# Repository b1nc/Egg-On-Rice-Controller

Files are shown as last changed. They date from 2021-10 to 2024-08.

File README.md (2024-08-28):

# Egg On Rice Controller
 Micro hitbox-style controller for arcade games. Utilizes the Brook UFB.
 Heavily inspired by the "Mille-feuille" by Pomeran. https://pomegd.booth.pm/items/2685530
-

**Why is it called "Egg On Rice"? I love egg on rice hell yeah.**

- *Feel free to modify the files to your needs and specifications but credit me for the original files, please.*

- *All of the parts used will be linked or named in the materials.txt file.*

- *The switch footprints were made with Kailh Choc v1 switches in mind.*

- *The keycaps may be too low and sit flush with the top acrylic panel. Please modify either the stem length or the blocker length to your needs.*

- *No RGB because it hurts my eyes. (I'm just too lazy to implement it.)*

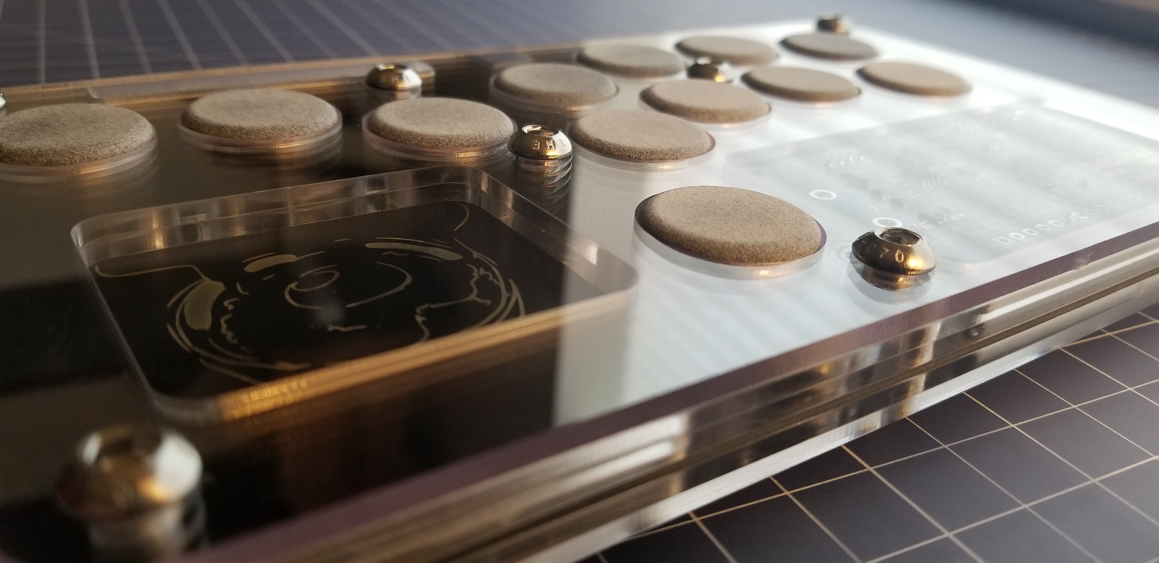
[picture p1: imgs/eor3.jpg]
eorimg1


 USB Type-C Connection because we live in 2020s A.D, not 2020s B.C. Micro USBs should just die.  
 (However, USB-Cs are a pain to hand solder, but again, I'm bad at soldering.)
 
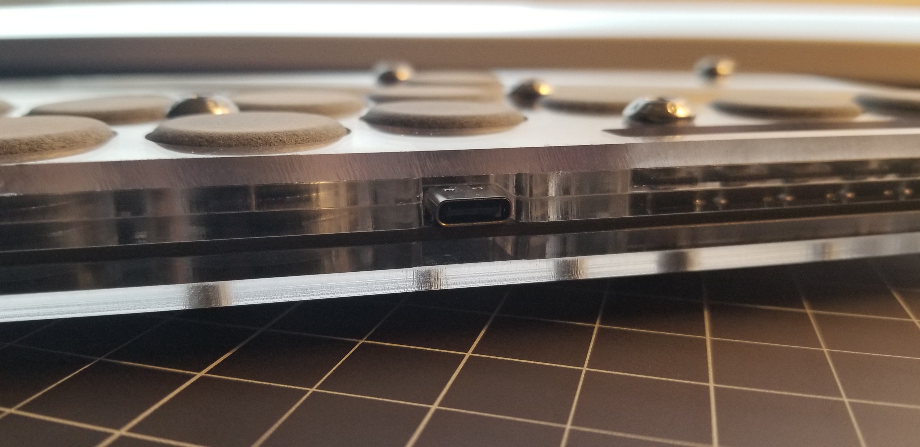
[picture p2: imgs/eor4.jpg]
eorimg2
 
 
 6 tactile push switches for menu navigations.  
 (I don't even own a PS4 or Xbox, what do these buttons even do.)  
 From left to right (in playing position): Home, Touchpad, LSB (huh), RSB (what), Share, Option (the only one I use).
 
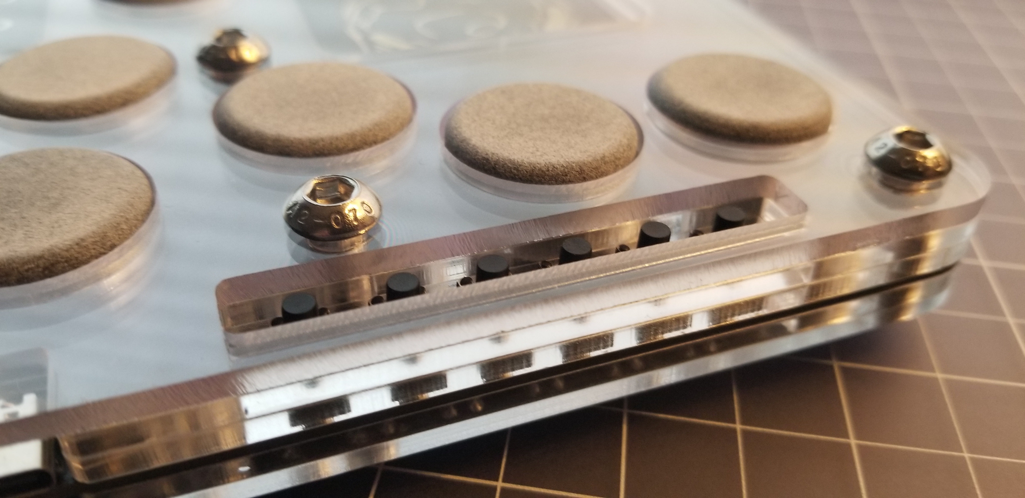
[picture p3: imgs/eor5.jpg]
 
 
 I couldn't find an M6 screw feet without sacrificing the overall thickness of the board, so I made the thing feetless.  
 (The back does kinda look clean, though.)
 
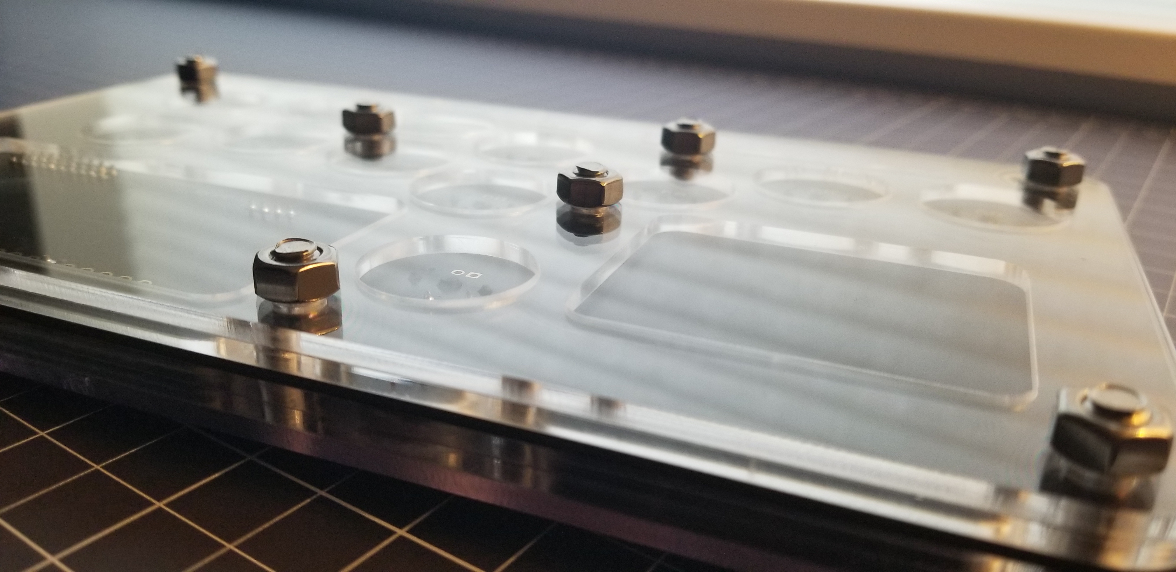
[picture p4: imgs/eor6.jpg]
 
 
 I'm sorry for my bad photography skills.  
   
 Here's a picture of the PCB using a PCB viewer.
 
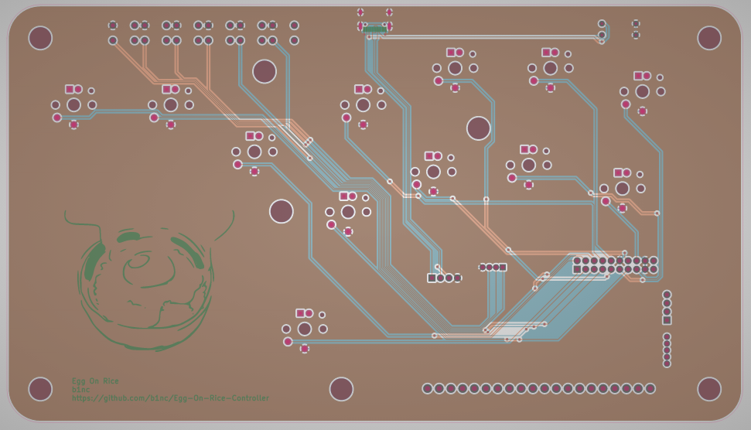
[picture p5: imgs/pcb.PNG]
   

 Buttons.
 
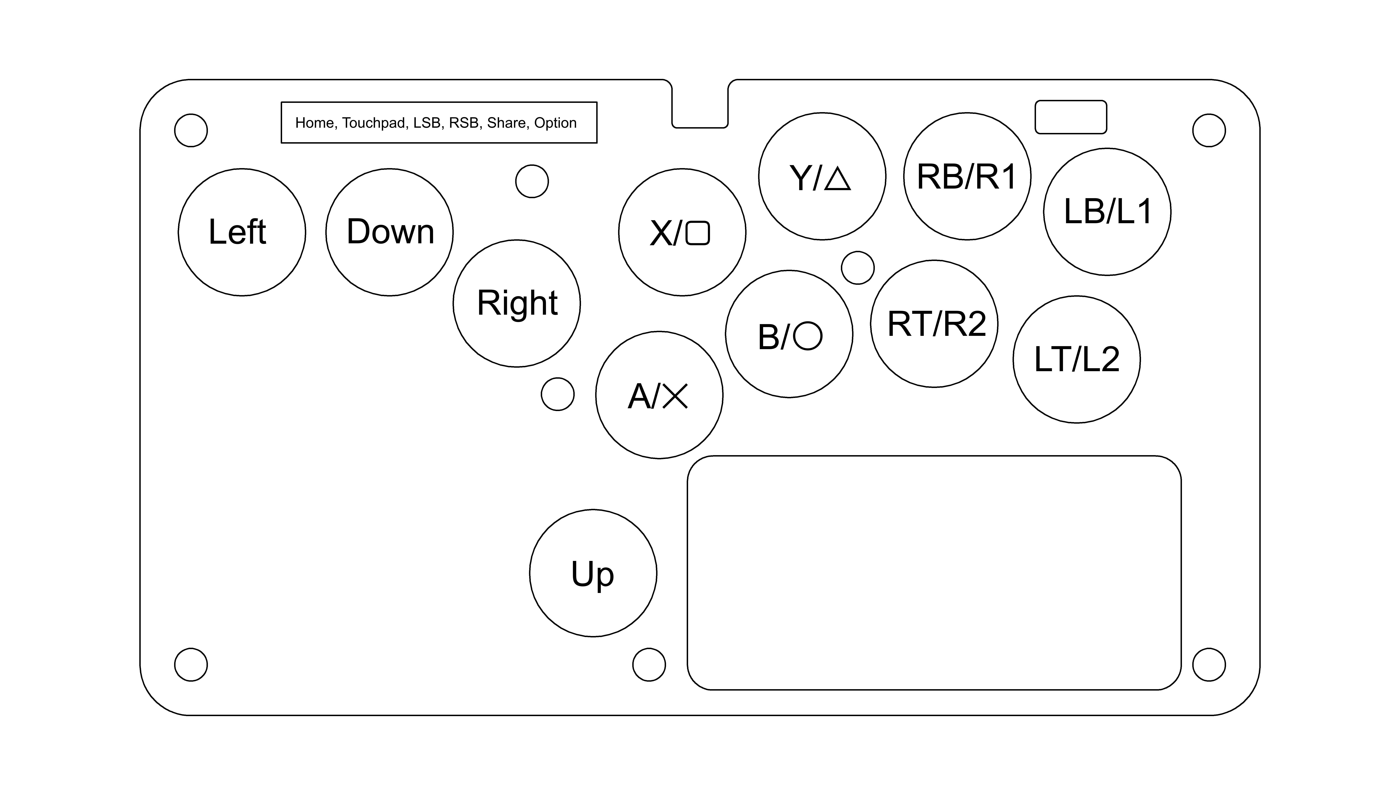
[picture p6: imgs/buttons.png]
  
  
## Design Process ##  
Started with a drawing of the basic outline and layout for the PCB (switches, resistors, push buttons, and UFB).  

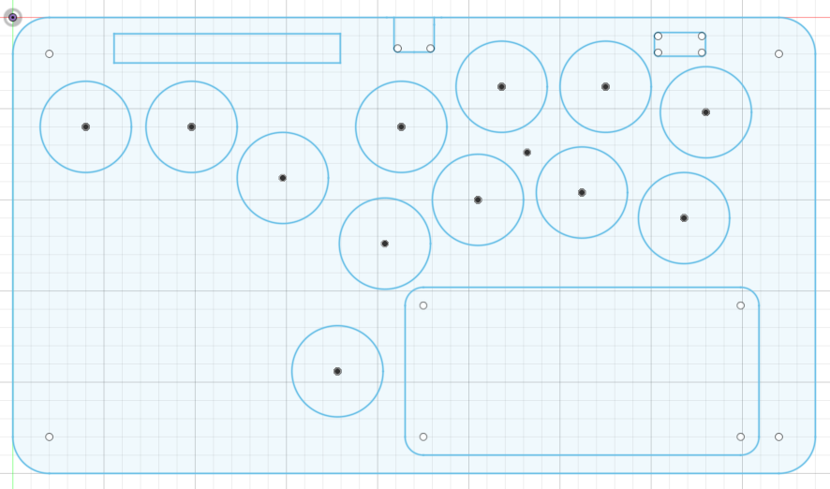
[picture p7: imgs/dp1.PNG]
  

Then exported the sketch as a dxf file and ported it into KiCad for component alignments.

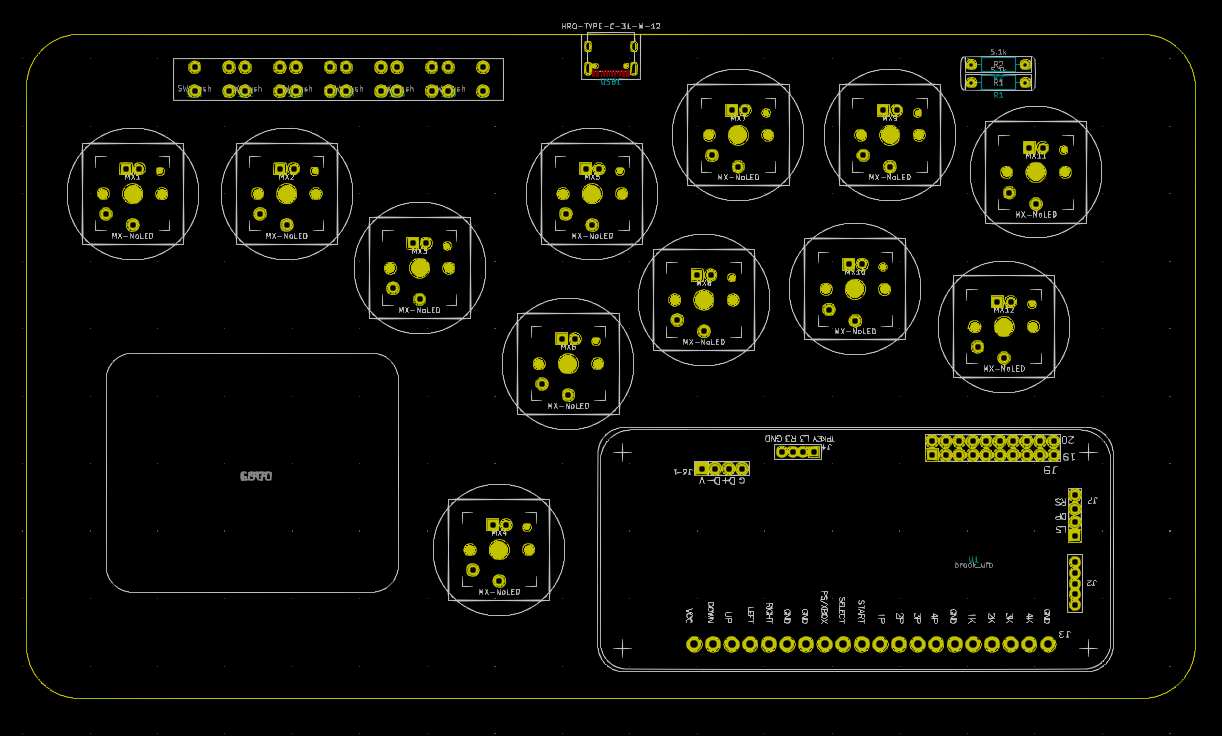
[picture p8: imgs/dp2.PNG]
  

The schematics for this PCB board are extremely simple. The only hard part was failing to find a UFB footprint and having to make my own. (UFB footprint is contained in this project and free to use, while it might not look good, it gets the job done.)

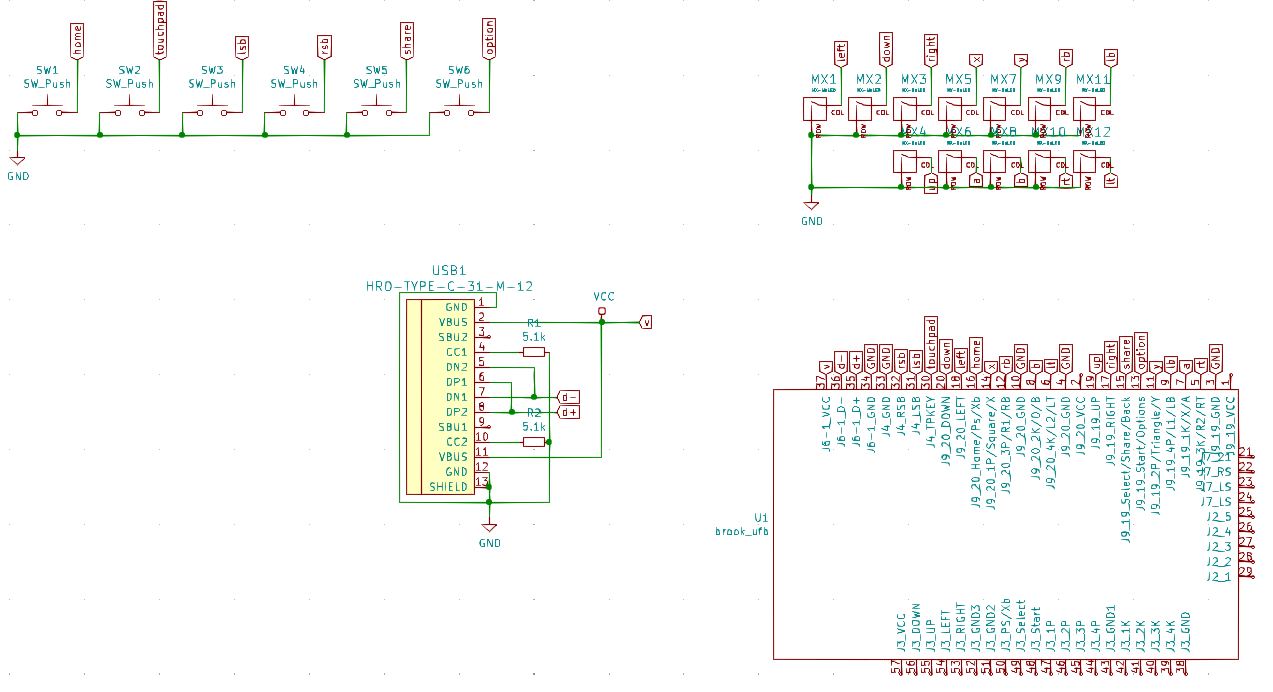
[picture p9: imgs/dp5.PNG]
  

After routing the board, edge cuts are added for M6 screw holes and artwork. (Feel free to edit the files to implement your personal artwork.)

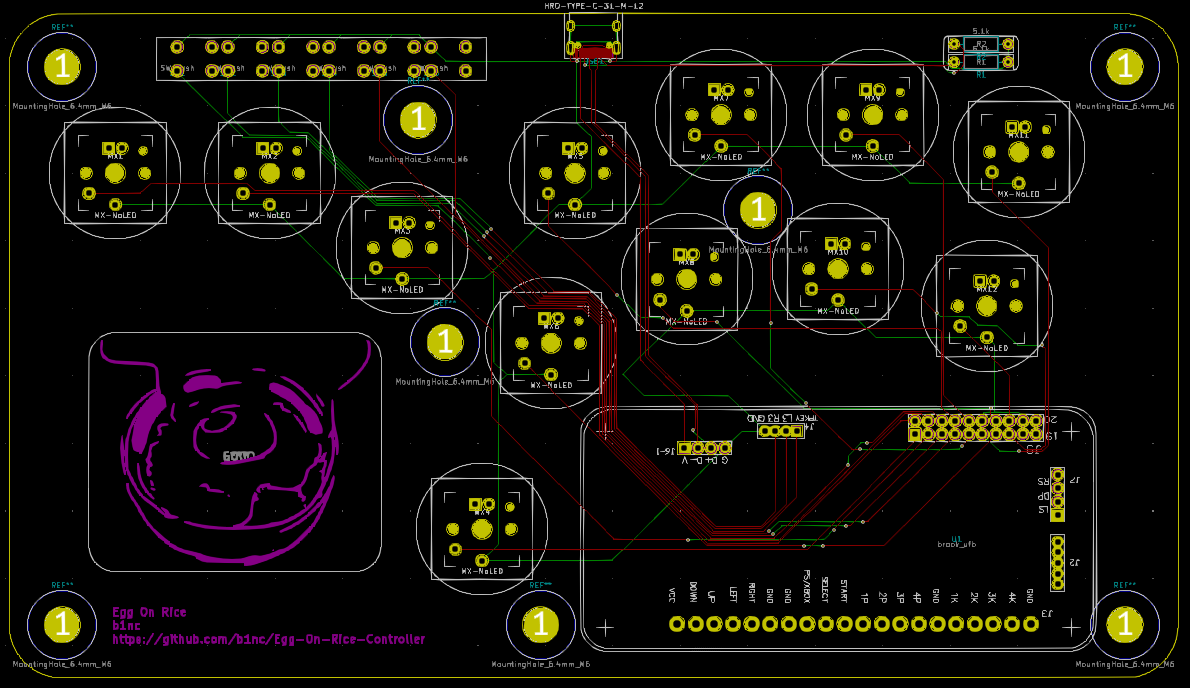
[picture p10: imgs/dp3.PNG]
  

Panel 1 and 2 are adjusted to fit with each other. If artwork isn't a concern, the bottom panel can also be used for the top panel to reduce cutting costs.

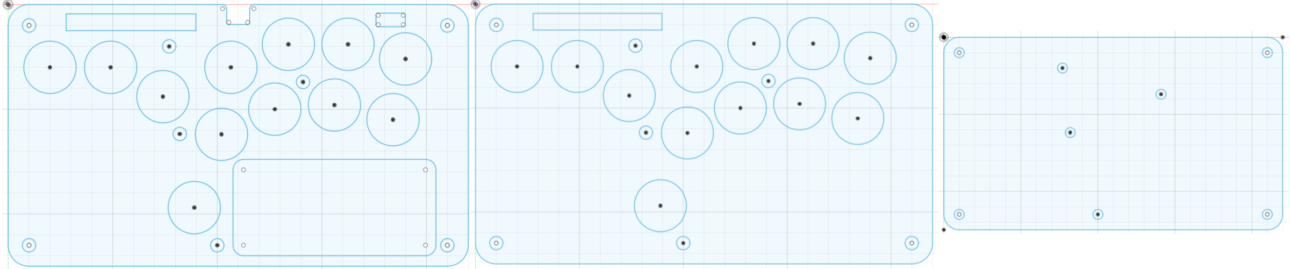
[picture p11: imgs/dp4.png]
  

Cap dimensions are made to fit almost flush with the top panels while the stems are made according to the Kailh Choc v1 datasheet.
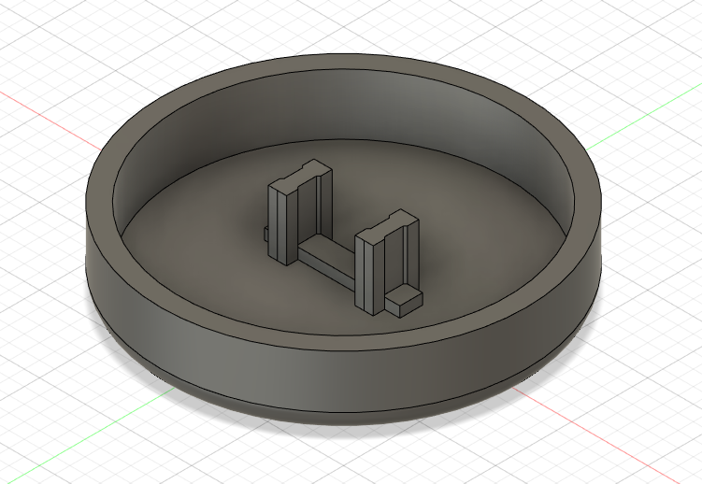
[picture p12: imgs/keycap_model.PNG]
  

## Building Instructions ##
All of the files needed are in this repo.

In the PCB folder, there's a Gerber.zip folder within the Gerber folder. Use this for PCB manufacturing.  
(I used JLCPCB for PCB prototyping.)  
  
In the Acrylic Layers folder, check which set of panels you want to use and use the dxf files for cutting.  
(Please refer to the drawing and readme for panel thickness and amount.)  
(I used SendCutSend laser cutting service for all my acrylic panels.)  
  
The button caps are made for Kailh Choc v1 switches and are in the Button Keycaps folder with both step and stl files available.  
(I don't plan on making keycaps for MX stems, but feel free to modify the files.)  
(Sculpteo has amazing prices for small 3D prints like these caps.)  

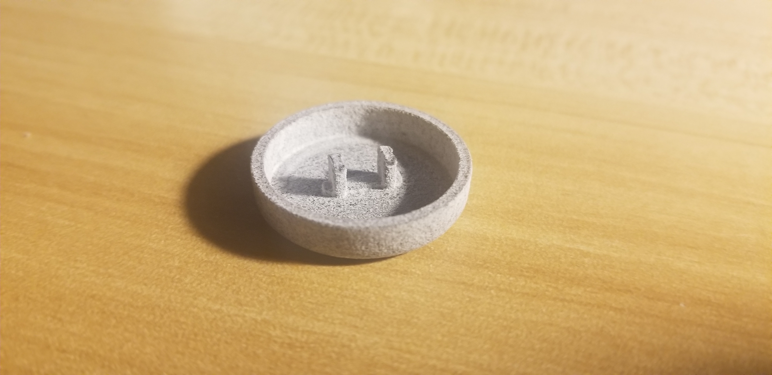
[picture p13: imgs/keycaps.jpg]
 
  
PCB assembly should be pretty straightforward. Two 5.1 kOhm resistors on the top right corner, 6 push tact. switches on the top left, and a USB Type-C connector.  
(USB Type-C connector was kind of tricky for me to solder, so I used a reflow station, instead.)  
(All components are through-hole except for the USB-C.)  
  
The UFB is connected by headers, and you should only need to solder the 2x10 button controls and the power joints.  
(You will need to desolder the UFB pin connectors and the USB B connector first.)  
(I recommend soldering the GND pins for the 1x20 pins as well so the UFB sits flush and stable.)  

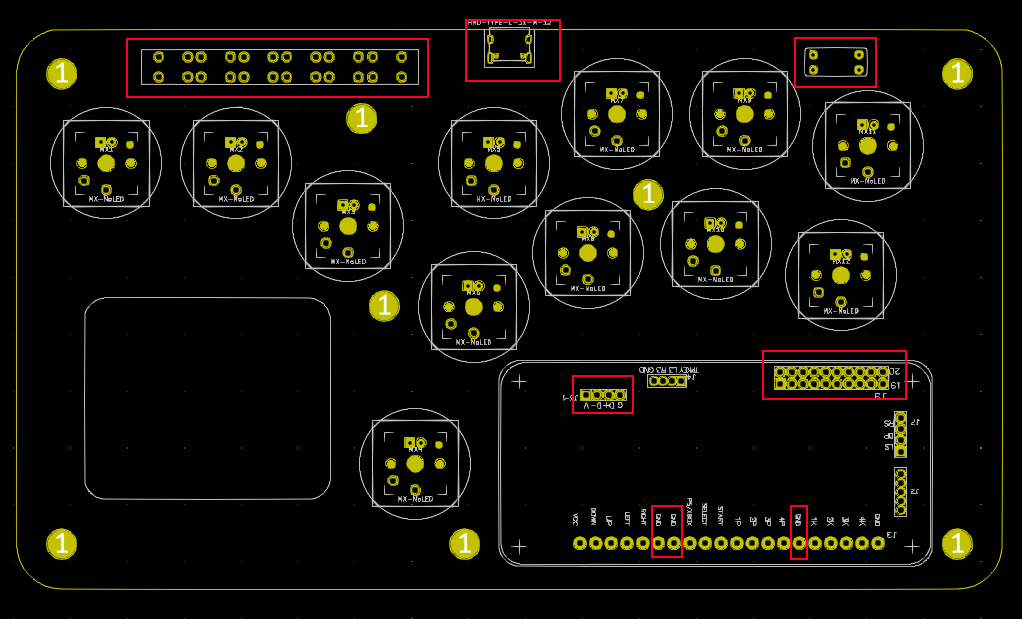
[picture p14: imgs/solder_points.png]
 
  
## Have fun making your very own hitbox-styled compact controller! :^) ##

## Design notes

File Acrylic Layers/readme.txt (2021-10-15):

Each acrylic panel (5 in total) should be 3 mm in thickness and the PCB board should be 1.6 mm in thickness.

However, change it according to your preferences. Just be aware that some other components might need to be changed as well to accomodate for the new height.

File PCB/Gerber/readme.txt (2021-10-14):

If you've made adjustments to the PCB and redid the Gerber files, please put them into the Gerber.zip folder as well.

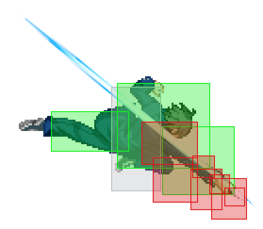
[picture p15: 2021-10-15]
imgs/funnee.png

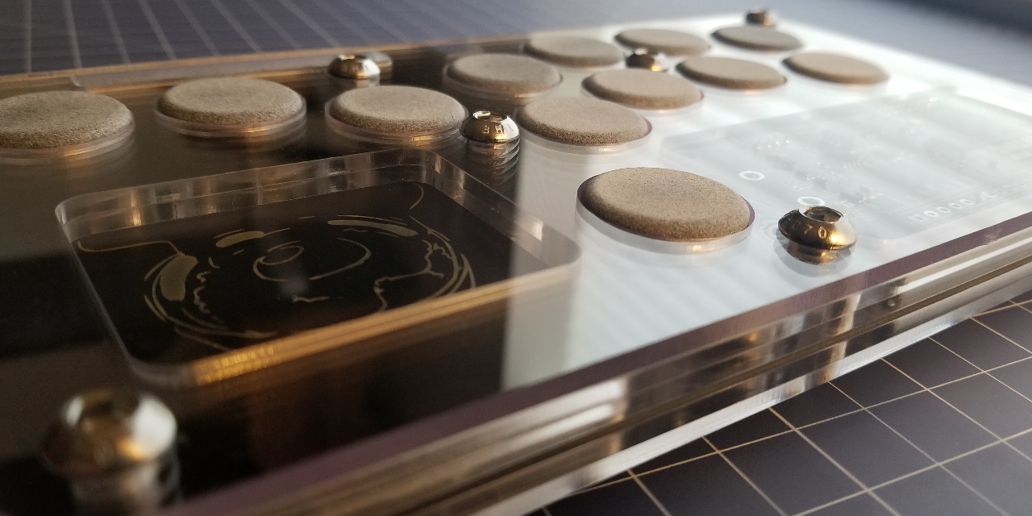
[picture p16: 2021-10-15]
imgs/preview_img.jpg

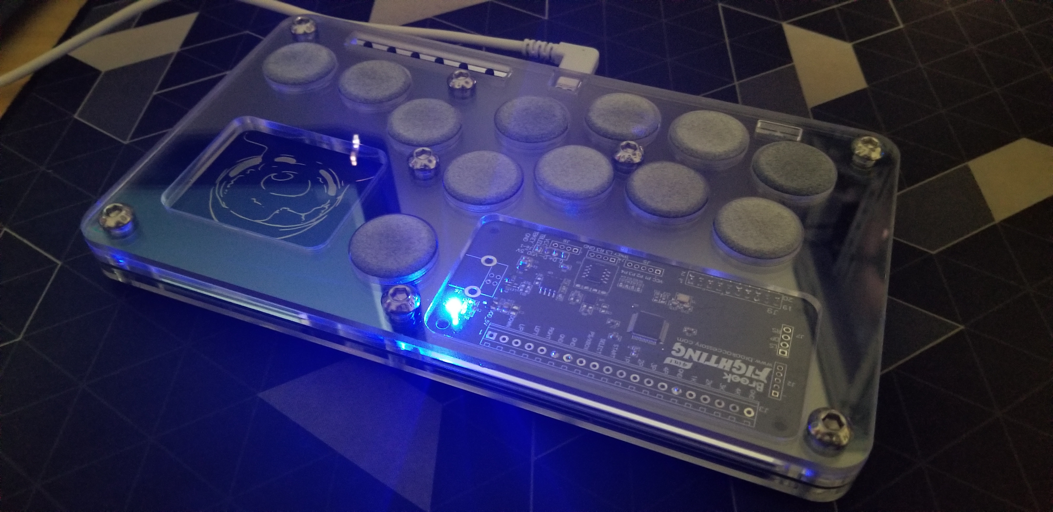
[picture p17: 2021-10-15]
imgs/eor2.jpg

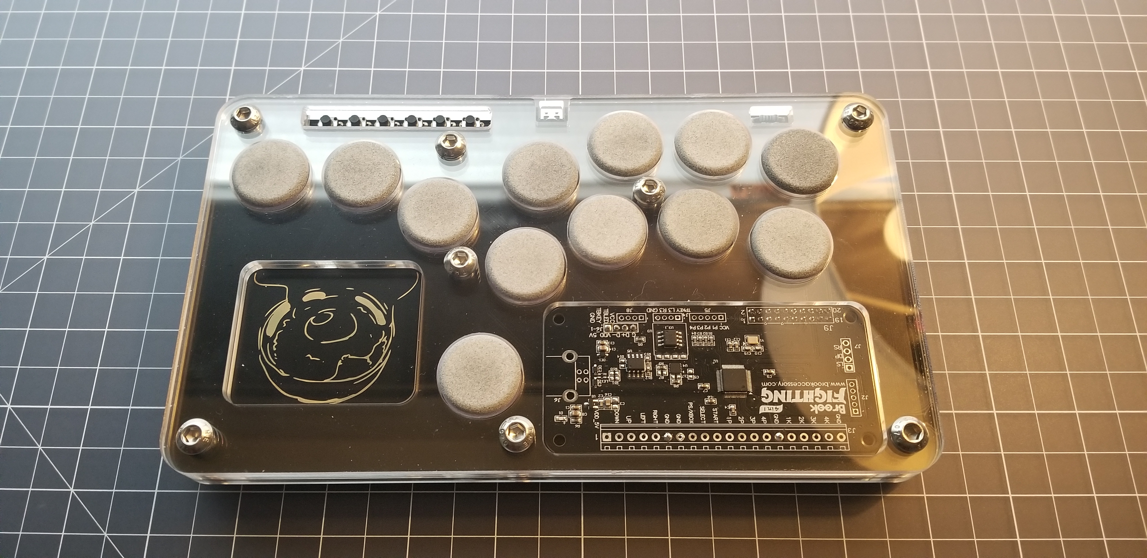
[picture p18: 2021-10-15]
imgs/eor1.jpg

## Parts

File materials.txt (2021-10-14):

Break-away header 0.1" (2x10 minimum [1], 1x1 [2]) (https://www.adafruit.com/product/2822)  (https://www.adafruit.com/product/392)

Kailh Low Profile Choc v1 Switches (12 switches minimum) (I used red linears to somewhat get close to the feels of Sanwa buttons but feel free to use other switches.)

22 mm M6 x 1 mm Thread (8 minimum) (https://www.mcmaster.com/92095A488/)

M6 x 1 mm Threat Nut (8 minimum) (https://www.mcmaster.com/91828A251/)

Tactile Switch SPST (6 minimum) (https://www.digikey.com/en/products/detail/1301.9304/486-3459-ND/7602713)

5.1 kOhms Through-hole Resistor (2 minimum) (https://www.digikey.com/en/products/detail/MBB02070C5101FCT00/BC3821CT-ND/7351251)

HRO TYPE-C-31-M-12 (1 minimum) (https://lcsc.com/product-detail/USB-Type-C_Korean-Hroparts-Elec-TYPE-C-31-M-12_C165948.html)

Brook Ultimate Fighting Board (1 minimum) (requires desoldering)

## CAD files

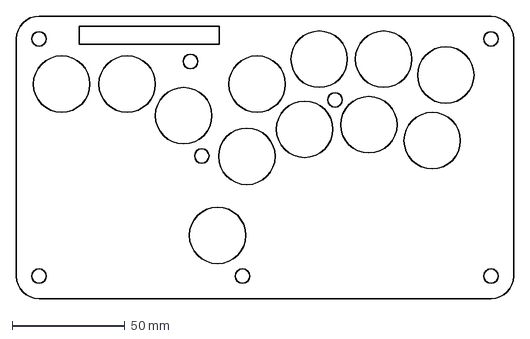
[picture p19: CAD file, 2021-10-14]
Acrylic Layers/Cutouts/egg_on_rice_layer+2cut.dxf
220.0 x 125.0 mm

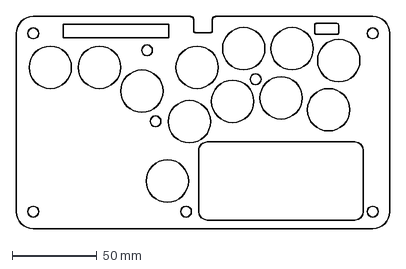
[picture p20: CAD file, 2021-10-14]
Acrylic Layers/No Cutouts/egg_on_rice_layer+-1.dxf
220.0 x 125.0 mm

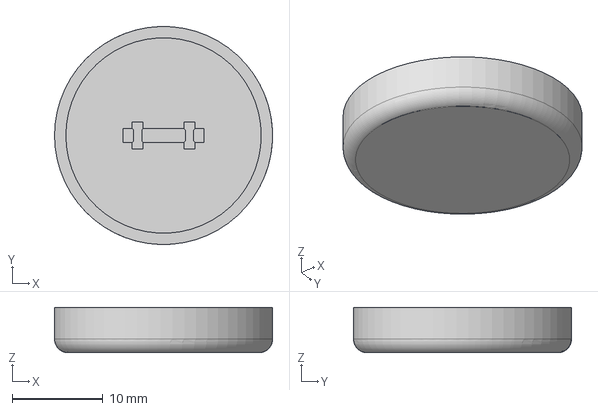
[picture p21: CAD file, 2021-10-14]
Button Keycaps/Egg on Rice Caps.step
24.0 x 24.0 x 5.00 mm

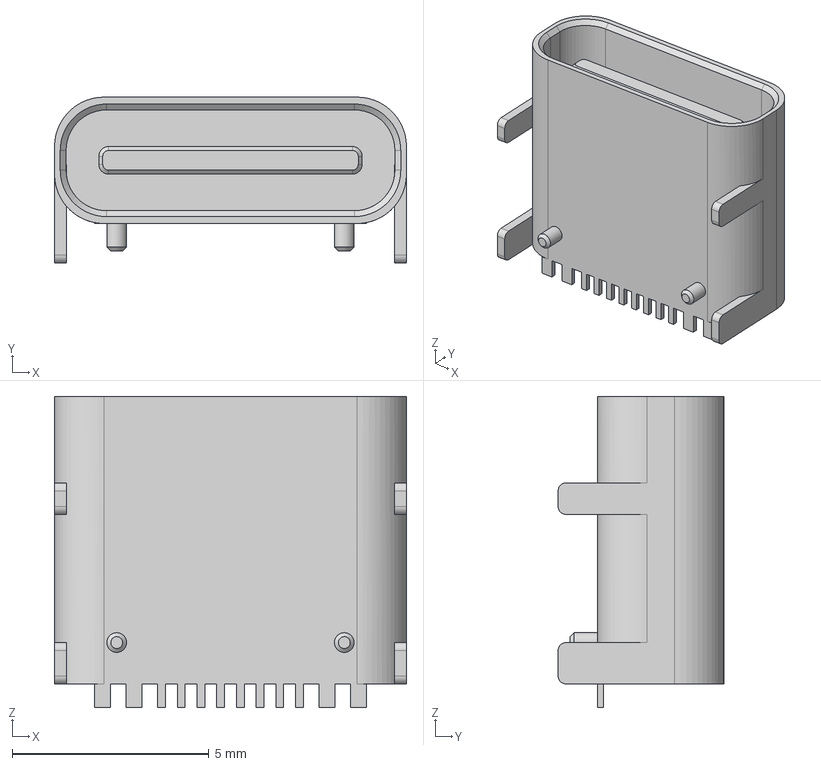
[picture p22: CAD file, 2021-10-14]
PCB/Footprints/Type-C.pretty-master/HRO TYPE-C-31-M-12.step
8.94 x 4.21 x 7.90 mm

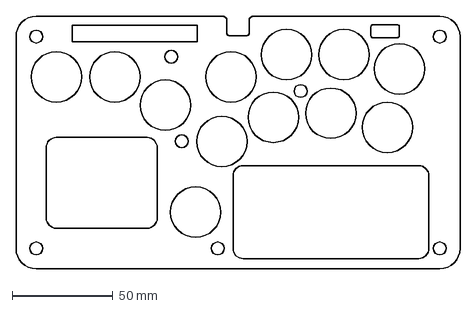
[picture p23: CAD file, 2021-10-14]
Acrylic Layers/Cutouts/egg_on_rice_layer+-1cut.dxf
220.0 x 125.0 mm

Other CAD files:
Acrylic Layers/Cutouts/egg_on_rice_layer-2cut.dxf
Acrylic Layers/No Cutouts/egg_on_rice_layer-2.dxf
Button Keycaps/Egg On Rice Caps.stl

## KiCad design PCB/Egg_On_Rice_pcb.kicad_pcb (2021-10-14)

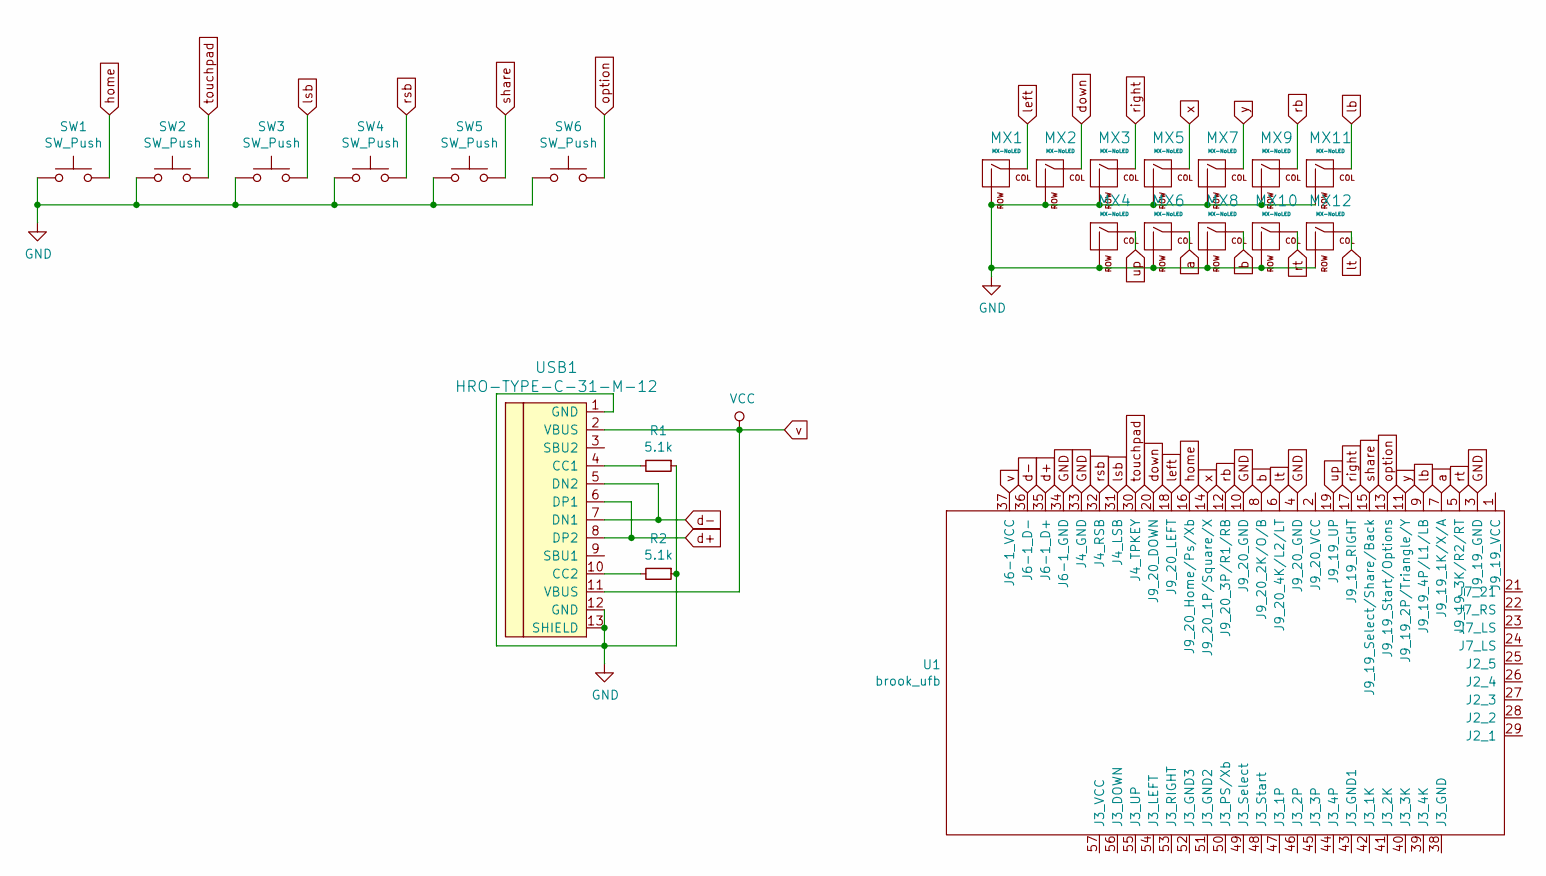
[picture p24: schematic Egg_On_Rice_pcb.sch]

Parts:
MX1, MX2, MX3, MX4, MX5, MX6, MX7, MX8, MX9, MX10, MX11, MX12: MX-NoLED; KailhChoc-1U
R1, R2: 5.1k; R_Axial_DIN0207_L6.3mm_D2.5mm_P10.16mm_Horizontal
SW1, SW2, SW3, SW4, SW5, SW6: SW_Push; spst_no_lph_6mm_6mm
U1: brook_ufb; Brook_Universal_Fighting_Board
USB1: HRO-TYPE-C-31-M-12

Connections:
GND: MX1.2 (ROW), MX2.2 (ROW), MX3.2 (ROW), MX4.2 (ROW), MX5.2 (ROW), MX6.2 (ROW), MX7.2 (ROW), MX8.2 (ROW), MX9.2 (ROW), MX10.2 (ROW), MX11.2 (ROW), MX12.2 (ROW), R1.1, R2.1, SW1.1, SW2.1, SW3.1, SW4.1, SW5.1, SW6.1, U1.3 (J9_19_GND), U1.4 (J9_20_GND), U1.10 (J9_20_GND), U1.33 (J4_GND), U1.34 (J6-1_GND), USB1.1 (GND), USB1.12 (GND), USB1.13 (SHIELD)
unnamed: R1.2, USB1.4 (CC1)
unnamed: R2.2, USB1.10 (CC2)
a: MX6.1 (COL), U1.7 (J9_19_1K/X/A)
b: MX8.1 (COL), U1.8 (J9_20_2K/O/B)
d+: U1.35 (J6-1_D+), USB1.6 (DP1), USB1.8 (DP2)
d-: U1.36 (J6-1_D-), USB1.5 (DN2), USB1.7 (DN1)
down: MX2.1 (COL), U1.20 (J9_20_DOWN)
home: SW1.2, U1.16 (J9_20_Home/Ps/Xb)
lb: MX11.1 (COL), U1.9 (J9_19_4P/L1/LB)
left: MX1.1 (COL), U1.18 (J9_20_LEFT)
lsb: SW3.2, U1.31 (J4_LSB)
lt: MX12.1 (COL), U1.6 (J9_20_4K/L2/LT)
option: SW6.2, U1.13 (J9_19_Start/Options)
rb: MX9.1 (COL), U1.12 (J9_20_3P/R1/RB)
right: MX3.1 (COL), U1.17 (J9_19_RIGHT)
rsb: SW4.2, U1.32 (J4_RSB)
rt: MX10.1 (COL), U1.5 (J9_19_3K/R2/RT)
share: SW5.2, U1.15 (J9_19_Select/Share/Back)
touchpad: SW2.2, U1.30 (J4_TPKEY)
up: MX4.1 (COL), U1.19 (J9_19_UP)
v: U1.37 (J6-1_VCC), USB1.2 (VBUS), USB1.11 (VBUS)
x: MX5.1 (COL), U1.14 (J9_20_1P/Square/X)
y: MX7.1 (COL), U1.11 (J9_19_2P/Triangle/Y)

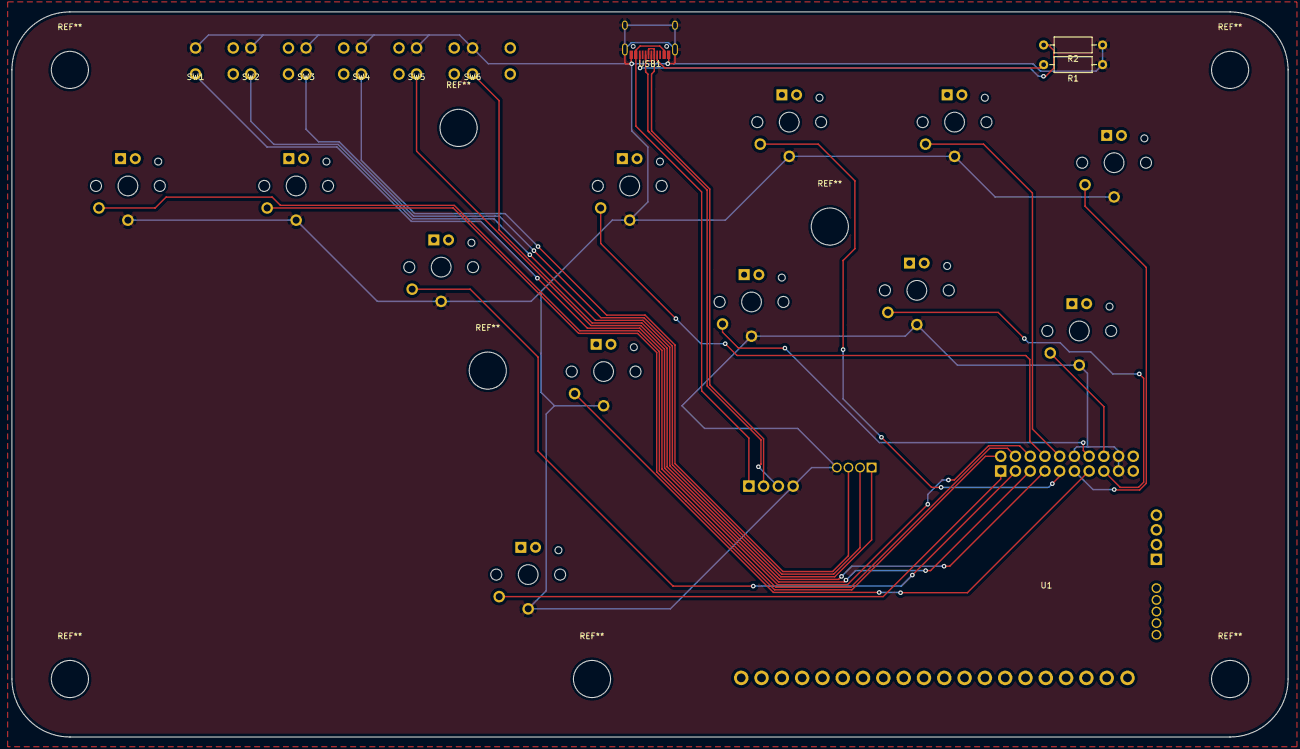
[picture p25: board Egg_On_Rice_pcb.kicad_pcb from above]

Board: 2 copper layers, 220.0 x 125.0 mm, 22 parts (0 on the bottom side), 24 nets.

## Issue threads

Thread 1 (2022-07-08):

Raspberry pi pico variant?

jh0nny2k, 2022-07-08:
Hi,

Any chance you can modify the pcb to incorporate a raspberry pi pico also ?

I would really like to make one for myself and basically i really really love your design. I already asked for pricing for the acrilic cutouts and i would like to order some pcb's.

Probably this would be beneficial for other people that also want to copy your design. Plus the brook boards are pretty expensive for the economy where i live in.

Kind regards,
Ionut

b1nc, 2022-07-08:
Hi there,

Thanks for your interest in my design.

Yes, adding a Raspberry Pi Pico footprint should be no problem. I'll do some research on it and work it out, but I won't be home until later this month so it will have to be a bit for the PCB to be finished.

I've also been planning on revising the USB-C connector, changing it to a removable daughterboard of some sort so the main board itself will not suffer any damage if the USB-C connector was to be ripped off (happened to me once but it was probably due to sloppy soldering).

Please tell me what you think about that and some other changes you'd like to see

jh0nny2k, 2022-07-08:
Thanks very much for taking a look at this.

When it's done it's done. Thank you for investing your time. Sounds good
about the usb type c connector.

I'll follow your project.

Kind regards,
Ionut

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

Closed 2022-07-08.
